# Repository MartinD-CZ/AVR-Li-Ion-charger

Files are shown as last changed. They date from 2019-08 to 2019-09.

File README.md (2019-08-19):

# AVR Li-Ion charger
*see the article [here](http://embedblog.eu/?p=392)*
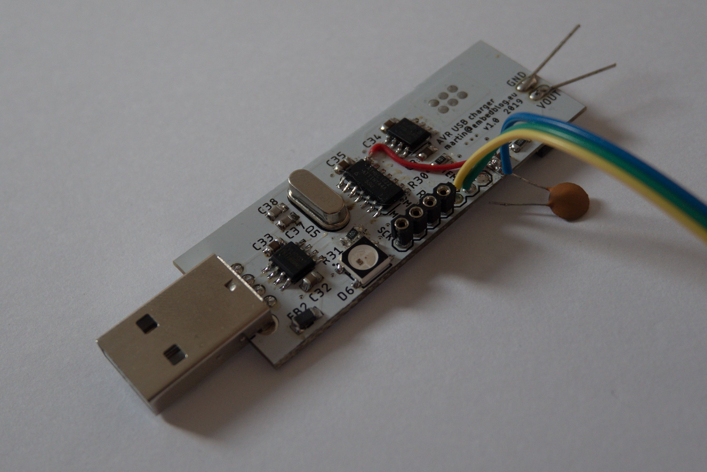
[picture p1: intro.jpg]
A picture of the finished device


ATtiny44-controlled buck converter with adjustable charging parameters (charging voltage & current, precharging voltage & current, min/max temperatures, ...). Everything is configurable via a serial port and stored in EEPROM.

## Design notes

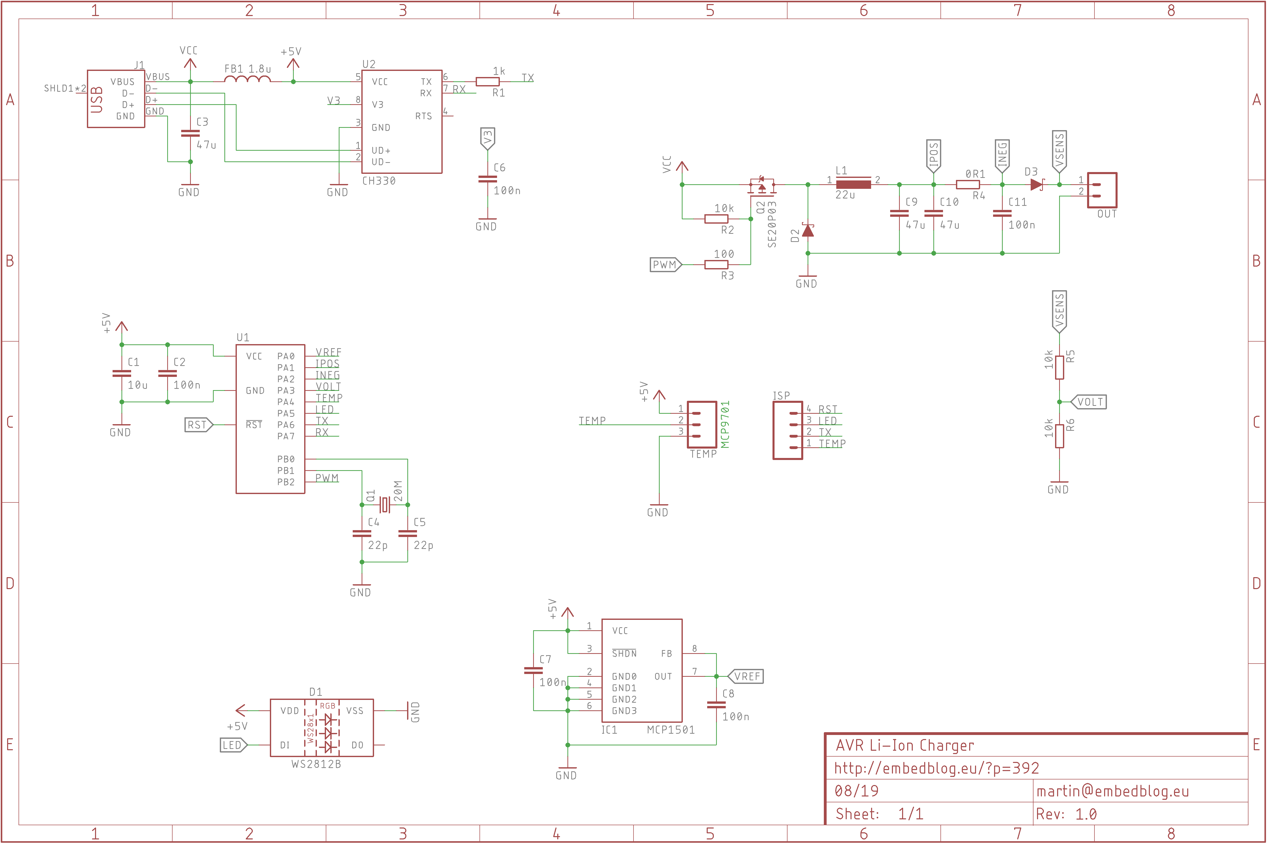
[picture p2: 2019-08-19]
hardware/schematics.png

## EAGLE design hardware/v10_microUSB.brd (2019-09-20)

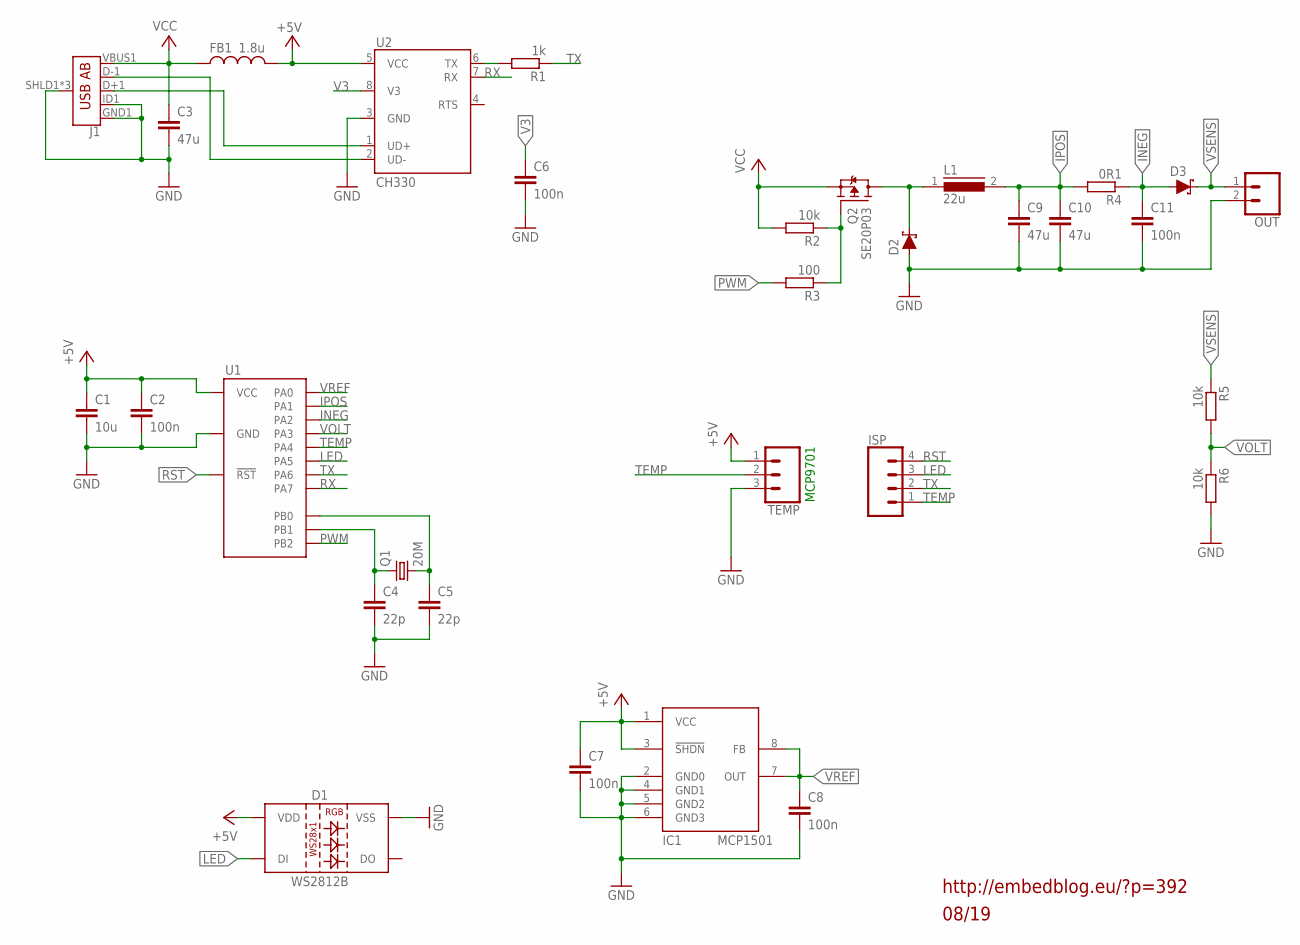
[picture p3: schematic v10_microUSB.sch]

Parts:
C1: 10u; C0805
C2, C6, C7, C8, C11: 100n; C0805
C3, C9, C10: 47u; C1206
C4, C5: 22p; C0805
D1: WS2812B
D2, D3: 3A/40V/500mV; SMA-DIODE
FB1: 1.8u; 1206
IC1: MCP1501; SO08
ISP: CONN_04; 1X04
J1: USB_AB_SMT; USB-AB-MICRO-SMD
L1: 22u; DR73
OUT: CONN_02PTH3; 1X02_LONGPADS
Q1: 20M; HC49/S
Q2: SE20P03; TO252
R1: 1k; R0805
R2, R5, R6: 10k; R0805
R3: 100; R0805
R4: 0R1; R1206
TEMP: 455-1750-1-ND; 1X03
U1: ATTINY24; SO014
U2: CH330; SO08

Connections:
+5V: C1.1, C2.1, C7.1, D1.1 (VDD), FB1.2, IC1.1 (VCC), IC1.3 (!SHDN), TEMP.1, U1.1 (VCC), U2.5 (VCC)
GND: C1.2, C2.2, C3.2, C4.2, C5.2, C6.2, C7.2, C8.2, C9.2, C10.2, C11.2, D1.3 (VSS), D2.A, IC1.2 (GND0), IC1.4 (GND1), IC1.5 (GND2), IC1.6 (GND3), J1.GND1 (GND), J1.ID1 (USBID), J1.SHLD1 (SHIELD), J1.SHLD2 (SHIELD), J1.SHLD3 (SHIELD), OUT.2, R6.2, TEMP.3, U1.14 (GND), U2.3 (GND)
INEG: C11.1, D3.A, R4.1, U1.11 (PA2)
IPOS: C9.1, C10.1, L1.2, R4.2, U1.12 (PA1)
LED: D1.4 (DI), ISP.3, U1.8 (PA5)
unnamed: R1.2, U2.6 (TX)
unnamed: C4.1, Q1.1, U1.3 (PB1)
unnamed: C5.1, Q1.2, U1.2 (PB0)
unnamed: Q2.1 (G), R2.1, R3.1
PWM: R3.2, U1.5 (PB2)
RST: ISP.4, U1.4 (!RST)
RX: U1.6 (PA7), U2.7 (RX)
SW: D2.C, L1.1, Q2.3 (D)
TEMP: ISP.1, TEMP.2, U1.9 (PA4)
TX: ISP.2, R1.1, U1.7 (PA6)
UD+: J1.D+1 (D+), U2.1 (UD+)
UD-: J1.D-1 (D-), U2.2 (UD-)
V3: C6.1, U2.8 (V3)
VCC: C3.1, FB1.1, J1.VBUS1 (VBUS), Q2.2 (S), R2.2
VOLT: R5.2, R6.1, U1.10 (PA3)
VREF: C8.1, IC1.7 (OUT), IC1.8 (FB), U1.13 (PA0)
VSENS: D3.C, OUT.1, R5.1

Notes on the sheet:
MCP9701
08/19
http://embedblog.eu/?p=392

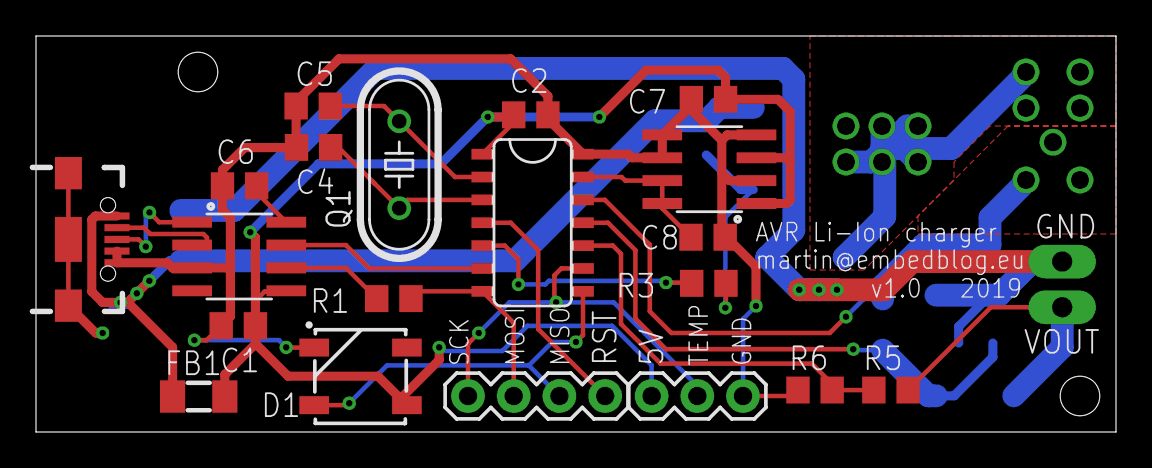
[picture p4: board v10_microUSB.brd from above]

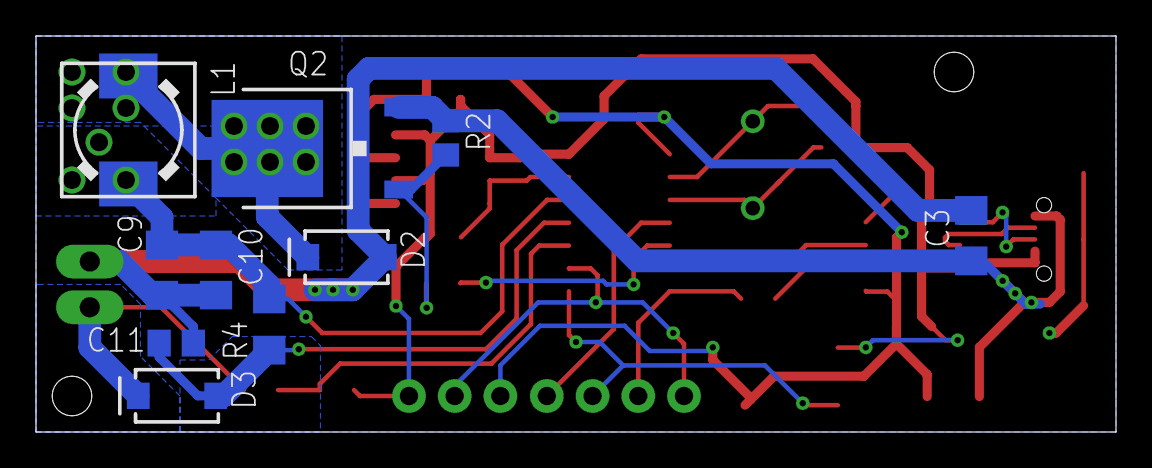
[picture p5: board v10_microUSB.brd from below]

Board: 2 copper layers, 60.0 x 22.0 mm, 31 parts (10 on the bottom side), 22 nets.

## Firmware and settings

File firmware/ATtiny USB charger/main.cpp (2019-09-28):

/*
 * ATtiny Li-Ion charger.cpp
 *
 * Created: 04.08.2019 23:07:01
 * Author: Martin Danek, martin@embedblog.eu
 * Fuses: low 0xFF, high 0xDF, ext 0xFF
 * License: CC BY-NC-SA 4.0 International
 */ 

#include <avr/io.h>
#include "defines.h"
#include <util/delay.h>
#include <avr/interrupt.h>
#include <avr/pgmspace.h>
#include <avr/wdt.h>
#include <stdlib.h>
#include "UART/uart.h"
#include "LED/ws2812.h"
#include "ADC/adc.h"
#include "portal.h"

uint16_t param[8];
uint16_t Vact, Iact, Itemp, Tact;

uint8_t color[3];		//GRB
bool precharge, temperature_sensor;

volatile uint16_t seconds;
volatile bool update;

extern volatile bool dataReady;

//disable watchdog on startup
void wdt_init(void) __attribute__((naked)) __attribute__((section(".init3")));

int main(void)
{
    _delay_ms(500);			//give some time to the serial terminal

	//init UART
	uart_init();
	uart_sendString_P(PSTR("\n\n\nSTART\n"));

	//init TIM1 - timekeeping
	TCCR1B = (1 << WGM12) | (1 << CS10) | (1 << CS11);
	OCR1A = 31250;
	TIMSK1 = (1 << OCIE1A);

	sei();

	//init LED
	DDRA |= (1 << DDA5);

	if (readEEPROM())
		uart_sendString_P(PSTR("Data loaded from EEPROM\n"));
	else
		uart_sendString_P(PSTR("Nothing in EEPROM, defaults used\n"));

	//check for temperature sensor
	if (adc_measurement(ADC_TEMP, 8) > 400)
	{
		temperature_sensor = true;
		uart_sendString_P(PSTR("Temperature sensor detected\n"));
	}
	else
		uart_sendString_P(PSTR("Temperature sensor not found\n"));

	//wait for user to connect the battery
	uart_sendString_P(PSTR("waiting for battery connection...\n"));
	while (1)
	{
		//we have something connected, skip setup
		if ((adc_measurement(ADC_VOUT, 8) * 2) > param[Vcon])
			break;

		//we have received something over serial, enter setup portal
		if (dataReady)
		{
			color[2] = 128;
			ws2812_sendarray_mask(color, 3, (1 << PA5), (uint8_t*)&PORTA, (uint8_t*)&DDRA);
			configPortal();
		}
		
		uart_sendString_P(PSTR("to start config, send anything via serial to the device; alternatively, connect a battery to start charging\n"));
		color[2] = 128;
		ws2812_sendarray_mask(color, 3, (1 << PA5), (uint8_t*)&PORTA, (uint8_t*)&DDRA);
		_delay_ms(500);
		color[2] = 0;
		ws2812_sendarray_mask(color, 3, (1 << PA5), (uint8_t*)&PORTA, (uint8_t*)&DDRA);
		_delay_ms(500);
	}

	//do we need to precharge?
	if ((adc_measurement(ADC_VOUT, 16) * 2) < param[Vpre])
	{
		precharge = true;
		Itemp = param[Imax];
		param[Imax] = param[Ipre];
	}

	//init TIM0 - 8 bit PWM @ 80 kHz
	TCCR0A = (1 << WGM00) | (1 << WGM01) | (1 << COM0A1) | (1 << COM0A0);
	DDRB |= (1 << DDB2);
	PWM_START;

	update = true;
    while (1)
    {
		Vact = adc_measurement(ADC_VOUT, 16) * 2;
		Iact = adc_measurement(ADC_IOUT, 16) / 2;

		//CC-CV regulation loop
		if (((Vact > param[Vmax]) | (Iact > param[Imax])) & (OCR0A > 0))
			OCR0A--;
		else if ((Vact < param[Vmax]) & (Iact < param[Imax]) & (OCR0A < 0xFF))
			OCR0A++;

		if (update)
		{
			update = false;

			if (temperature_sensor)
				Tact = (((uint16_t)adc_measurement(ADC_TEMP, 8) - 400) / 20);

			uart_sendString_P(PSTR("Vout: "));
			uart_sendNumber(Vact);
			uart_sendString_P(PSTR(" mV; Iout: "));
			uart_sendNumber(Iact);
			uart_sendString_P(PSTR(" mA"));
			if (temperature_sensor)
			{
				uart_sendString_P(PSTR("; t: "));
				uart_sendNumber(Tact);
				uart_sendString_P(PSTR(" C"));
			}
			uart_sendString_P(PSTR("\n"));

			//precharge-CC-CV-finished determination loop
			int16_t Vdelta = param[Vmax] - Vact;
			int16_t Idelta = param[Imax] - Iact;
			if (precharge)
			{
				//precharge - purple color
				color[0] = 35; color[1] = 80; color[2] = 80;
				ws2812_sendarray_mask(color, 3, (1 << PA5), (uint8_t*)&PORTA, (uint8_t*)&DDRA);

				//are the conditions for precharging still true?
				if ((adc_measurement(ADC_VOUT, 16) * 2) > param[Vpre])
				{
					precharge = false;
					param[Imax] = Itemp;
				}
			}
			else if (abs(Vdelta) >= abs(Idelta))
			{
				//CC mode - red color
				color[0] = 0; color[1] = 128; color[2] = 0;
				ws2812_sendarray_mask(color, 3, (1 << PA5), (uint8_t*)&PORTA, (uint8_t*)&DDRA);
			}
			else
			{
				//CV mode
				if (Iact < param[Icut])
				{
					//we are finished - green color
					PWM_STOP;
					color[0] = 128; color[1] = 0; color[2] = 0;
					ws2812_sendarray_mask(color, 3, (1 << PA5), (uint8_t*)&PORTA, (uint8_t*)&DDRA);
					uart_sendString_P(PSTR("==FINISHED==\n"));
					while (1);
				}
			
				//we are not finished - orange color
				color[0] = 50; color[1] = 128; color[2] = 0;
				ws2812_sendarray_mask(color, 3, (1 << PA5), (uint8_t*)&PORTA, (uint8_t*)&DDRA);
			}

			//temperature check
			if (((Tact > param[Tmax]) | (Tact < Tmin)) && temperature_sensor)
			{
				PWM_STOP;
				uart_sendString_P(PSTR("TEMPERATURE ERROR\n"));
				color[0] = 0; color[2] = 0;
				while(1)
				{
					color[1] = 128;
					ws2812_sendarray_mask(color, 3, (1 << PA5), (uint8_t*)&PORTA, (uint8_t*)&DDRA);
					_delay_ms(500);
					color[1] = 0;
					ws2812_sendarray_mask(color, 3, (1 << PA5), (uint8_t*)&PORTA, (uint8_t*)&DDRA);
					_delay_ms(500);
				}
			}
		}
    }
}

//interrupt each 100 ms
volatile uint8_t OVF_counter;
ISR(TIM1_COMPA_vect)
{
	OVF_counter++;
	if (OVF_counter >= 10)
	{
		OVF_counter = 0;
		seconds++;
		update = true;
	}
}

void wdt_init(void)
{
	MCUSR = 0;
	wdt_disable();
}

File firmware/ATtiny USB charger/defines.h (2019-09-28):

/*
 * defines.h
 */ 


#ifndef DEFINES_H_
#define DEFINES_H_

#define F_CPU			20000000UL

#define PWM_START		TCCR0B = (1 << CS00)
#define PWM_STOP		TCCR0B = 0x00; DDRB &=~(1 << PB2)

#define STX_HIGH		PORTA |= (1 << PA7)
#define STX_LOW			PORTA &=~(1 << PA7)
#define SRX_LOW			!(PINA & (1 << PINA6))
#define SUART_BAUD		19200

#define SUART_DELAY		1000000/SUART_BAUD

#define Vmax			0
#define Vpre			1
#define Imax			2
#define Icut			3
#define Ipre			4
#define Vcon			5
#define Tmin			6
#define Tmax			7

#endif /* DEFINES_H_ */

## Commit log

2019-08-19 V1.0 - initial
    initial release
    [v10.brd, v10.sch]
2019-09-20 V1.0B
    added microUSB version; code optimization; layout optimization for better thermals
    [v10_microUSB.brd, v10_microUSB.sch]
2019-09-28 V1.0C
    minor fixes & improvements for temperature sensor detection
    [defines.h, main.cpp, portal.cpp]

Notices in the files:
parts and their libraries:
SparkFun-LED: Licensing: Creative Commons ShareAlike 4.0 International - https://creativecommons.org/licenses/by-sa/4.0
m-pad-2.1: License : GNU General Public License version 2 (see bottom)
